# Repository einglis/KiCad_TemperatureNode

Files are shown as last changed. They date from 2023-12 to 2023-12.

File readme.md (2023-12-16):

# Temperature Hub

A little board with a few connections for one-wire DS temperature sensors.

Code is included for completeness only

## HW mods
After production, I discovered that A6 and A7 can't be used for digital IOs, so I bodge-wired them to D4 and D3, repectively.  This is reflected in the schematic and code but not the PCB or gerbers.

## Dependencies
* https://github.com/hulkco/Nano_33/tree/master
* rfm12b symbol from ...??

## Pictures
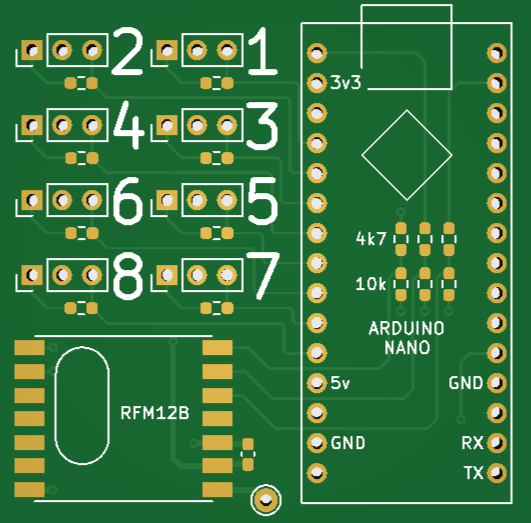
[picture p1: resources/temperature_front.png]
front

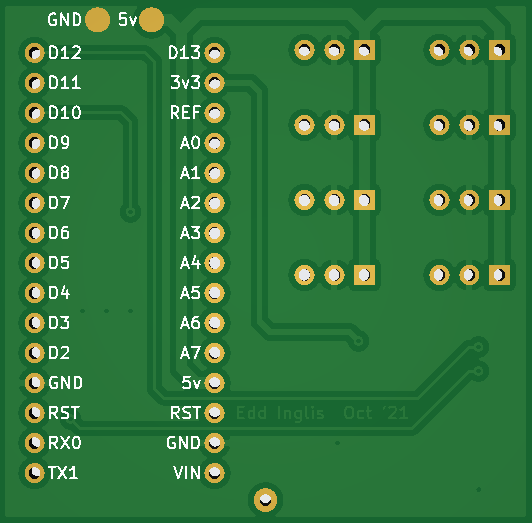
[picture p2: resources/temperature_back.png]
back


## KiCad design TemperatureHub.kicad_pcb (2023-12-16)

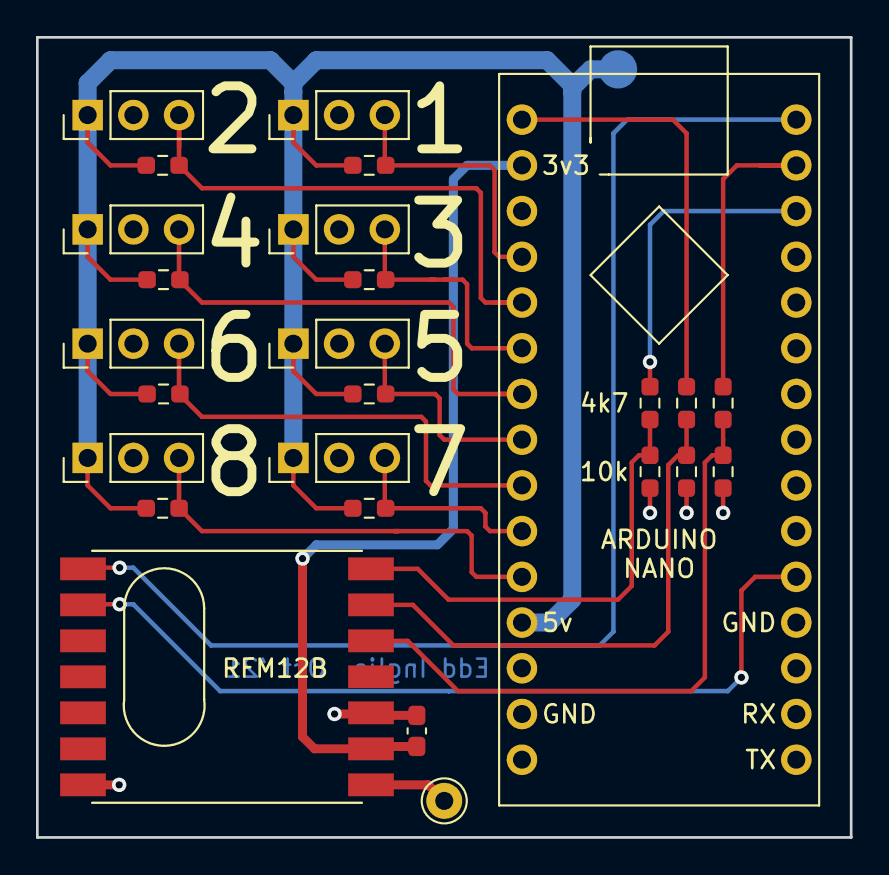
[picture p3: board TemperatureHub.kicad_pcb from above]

Board: 2 copper layers, 45.2 x 44.4 mm, 26 parts (0 on the bottom side), 20 nets.

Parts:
C1: 0.1uF; C_0603_1608Metric_Pad1.08x0.95mm_HandSolder
J1: Arduino-NANO-33; NANO_33_Socket_Normal
J2, J4, J5, J6, J7, J8, J9, J10: Conn_01x03_Male; PinHeader_1x03_P2.54mm_Vertical
J3: Conn_01x01_Male; Pin_D1.0mm_L10.0mm
R1, R3, R5, R7, R8, R9, R10, R11, R12, R13, R14: 4k7; R_0603_1608Metric_Pad0.98x0.95mm_HandSolder
R2, R4, R6: 10k; R_0603_1608Metric_Pad0.98x0.95mm_HandSolder
U1: RFM12; rfm12b

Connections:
+3V3: C1.1, J1.2, U1.VDD
+5V: J1.12, J2.1, J4.1, J5.1, J6.1, J7.1, J8.1, J9.1, J10.1, R7.1, R8.1, R9.1, R10.1, R11.1, R12.2, R13.1, R14.1
/sensor0: J1.4, J4.3, R8.2
/sensor1: J1.5, J8.3, R12.1
/sensor2: J1.6, J2.3, R7.2
/sensor3: J1.7, J5.3, R9.2
/sensor4: J1.8, J6.3, R10.2
/sensor5: J1.9, J7.3, R11.2
/sensor6: J1.10, J9.3, R13.2
/sensor7: J1.11, J10.3, R14.2
GND: C1.2, J1.14, J1.19, J2.2, J4.2, J5.2, J6.2, J7.2, J8.2, J9.2, J10.2, R2.2, R4.2, R6.2, U1.GND
unnamed: J1.1, R1.2
unnamed: J1.20, U1.IRQ
unnamed: J1.28, R5.2
unnamed: J1.29, R3.2
unnamed: J1.30, U1.SDO
unnamed: J3.1, U1.ANT
unnamed: R1.1, R2.1, U1.SCK
unnamed: R3.1, R4.1, U1.SDI
unnamed: R5.1, R6.1, U1.SEL

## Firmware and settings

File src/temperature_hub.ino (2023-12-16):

// Based on work from Rob Tillaart
// http://forum.arduino.cc/index.php?topic=216835.msg1764333#msg1764333

#define RF69_COMPAT 1
#include <JeeLib.h>

#include <OneWire.h>
#include <DallasTemperature.h>

#define NUM_SENSORS 8

OneWire oneWire_a0(A0);
OneWire oneWire_a1(A1);
OneWire oneWire_a2(A2);
OneWire oneWire_a3(A3);
OneWire oneWire_a4(A4);
OneWire oneWire_a5(A5);
OneWire oneWire_a6(4); // bodge wired since A6 can't be used as digital IO
OneWire oneWire_a7(3); // likewise A7

DallasTemperature sensor_a0(&oneWire_a0);
DallasTemperature sensor_a1(&oneWire_a1);
DallasTemperature sensor_a2(&oneWire_a2);
DallasTemperature sensor_a3(&oneWire_a3);
DallasTemperature sensor_a4(&oneWire_a4);
DallasTemperature sensor_a5(&oneWire_a5);
DallasTemperature sensor_a6(&oneWire_a6);
DallasTemperature sensor_a7(&oneWire_a7);

DallasTemperature* sensors[ NUM_SENSORS ] = { 
    &sensor_a0, &sensor_a1, &sensor_a2, &sensor_a3, 
    &sensor_a4, &sensor_a5, &sensor_a6, &sensor_a7, 
};



void setup(void)
{
    Serial.begin(115200);
    Serial.println("Dallas Temperature 8x Board");

    for (int i = 0; i < NUM_SENSORS; i++)
        sensors[i]->begin();

    rf12_initialize( 22/*nodeID*/, RF12_433MHZ, 210/*networkGroup*/);
    //rf12_sleep( RF12_SLEEP );
        // XXXEDD: sleeping and waking up seems to be the right thing to do,
        // but it was causing the 3rd byte to be lost occasionally (often),
        // leading to corrupt messages.  I don't know why, but since we're
        // not power-limited, just remain awake.
}


void send_rf_data( const void* data, const int data_len )
{
  rf12_sendNow( 0, data, data_len );
  rf12_sendWait( 0 /*powerdown mode, was 2*/ );
}


void loop(void)
{
    static long last_send = millis();
    if (millis() - last_send < 5000)
        return;
    
    Serial.print("Requesting temperatures...");
    for (int i = 0; i < NUM_SENSORS; i++)
        sensors[i]->requestTemperatures();
    Serial.println(" done");

    int temps[ NUM_SENSORS ];

    for (int i = 0; i < NUM_SENSORS; i++)
    {
        temps[i] = sensors[i]->getTempCByIndex(0)*100;
      
        Serial.print("Temperature "); 
        Serial.print(i+1);
        Serial.print(": "); 
        Serial.print((float)temps[i]/100);
        Serial.println(" degC"); 
    }

    send_rf_data( temps, sizeof(temps) );
    last_send = millis();
}

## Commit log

2023-12-16 Restoring to working order, hopefully
    [TemperatureHub.kicad_sch]
2023-12-16 is committing a .zip of gerbers such a sin?!
2023-12-16 I think this was an old format that KiCad replace with kicad_sch
    [TemperatureHub.sch]
2023-12-16 moved the gerbers
